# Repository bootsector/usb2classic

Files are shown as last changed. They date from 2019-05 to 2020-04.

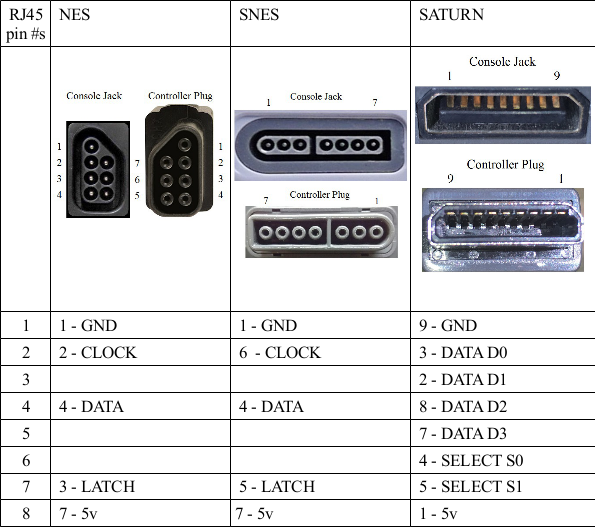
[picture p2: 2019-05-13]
doc/rj45_output_cables.png

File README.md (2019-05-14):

# USB2Classic - USB controllers adapter for retro consoles!
(c) Bruno Freitas - 04/2019 - http://www.brunofreitas.com/  

This project is Open Source (GPLv3) and Open Hardware (CC BY-SA 4.0)  

I've bought some super-cheap STM8S 8-bit microcontroller based boards and I 
was wondering what kind of cool project I could put them to use. I've mixed
it with an USB Host Mini 2.0 module a CPLD and some discrete components and
then the USB2Classic adapter was born!

This adapter allows you to use USB controllers with old consoles, such as:

* Sega Genesis / Mega Drive (can emulate either a 3 button or 6 button pad)
* Sega Master System, Atari 2600 and others
* Panasonic 3DO
* NES
* Super NES
* Sega Saturn
* Neo Geo
* TG16/PC-Engine (through adapter board connected to the Neo Geo output)

Currently compatible USB controllers are:

* Playstation 4 USB controller
* XBOX 360 USB controller (and compatible XInput devices)
* XBOX 360 USB Wireless Receiver
* 8BitDo Wireless USB Adapter (in XInput mode)
* Some PS3/PS4/XBOX360 USB arcade stick controllers

The CPLD originally used by this adapter is an EPM7064SLC44-10N which is 5V
based. Verilog sources are inside the multi-out directory along with Quartus II
project files.

The USB Host Mini board **MUST** be modified for 5V as shown in the
doc/usbhost_mini_5v_mod.png diagram.

Firmware was compiled using SDCC version 3.8.0

Thanks to Bruno Duarte Gouveia (brNX) for all the help with Verilog!

Enjoy!

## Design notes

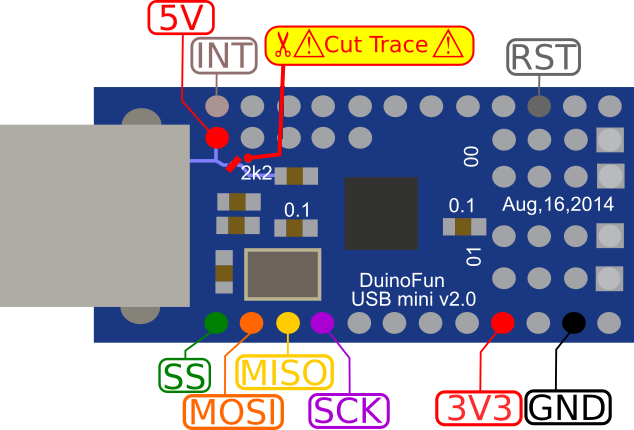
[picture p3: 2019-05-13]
doc/usbhost_mini_5v_mod.png

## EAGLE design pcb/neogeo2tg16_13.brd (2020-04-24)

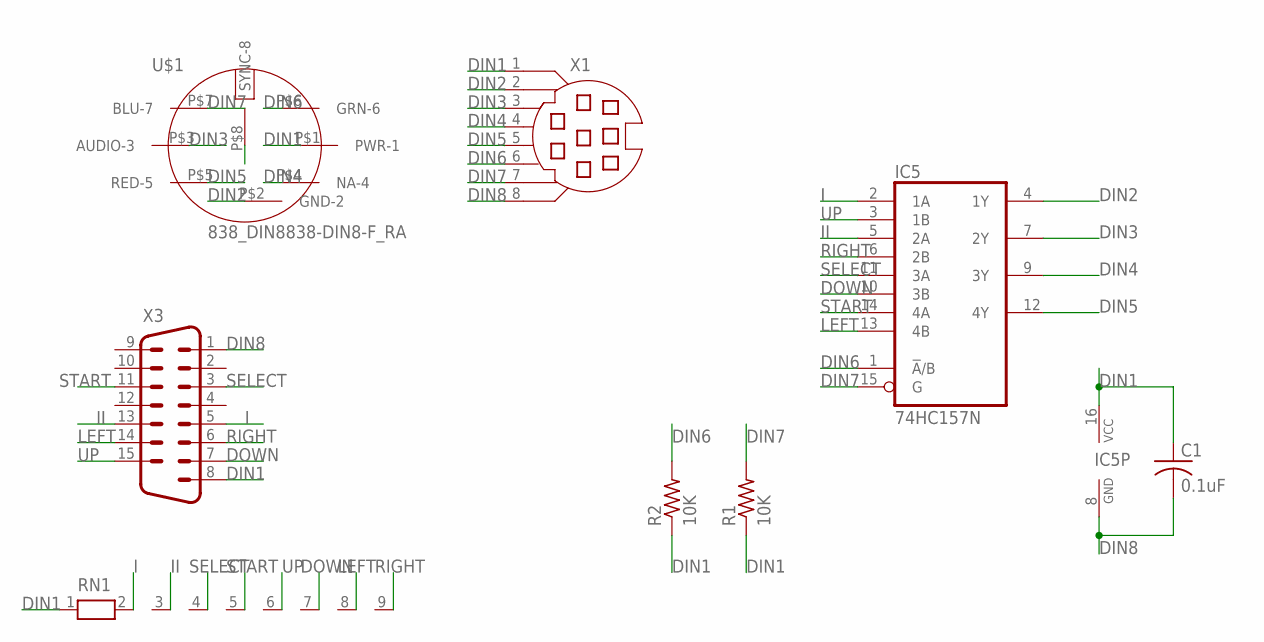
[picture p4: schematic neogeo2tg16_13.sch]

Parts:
C1: 0.1uF; C025-024X044
IC5: 74HC157N; DIL16
R1, R2: 10K; 0204/7
RN1: RN08; RN-9
U$1: 838_DIN8838-DIN8-F_RA; 838_DIN8
X1: MD08SS; MDIN08SS
X3: M15HP

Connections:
DIN1: C1.1, IC5.16 (VCC), R1.1, R2.1, RN1.1, U$1.P$1 (PWR-1), X1.1, X3.8
DIN2: IC5.4 (1Y), U$1.P$2 (GND-2), X1.2
DIN3: IC5.7 (2Y), U$1.P$3 (AUDIO-3), X1.3
DIN4: IC5.9 (3Y), U$1.P$4 (NA-4), X1.4
DIN5: IC5.12 (4Y), U$1.P$5 (RED-5), X1.5
DIN6: IC5.1 (!A!/B), R2.2, U$1.P$6 (GRN-6), X1.6
DIN7: IC5.15 (G), R1.2, U$1.P$7 (BLU-7), X1.7
DIN8: C1.2, IC5.8 (GND), U$1.P$8 (SYNC-8), X1.8, X3.1
DOWN: IC5.10 (3B), RN1.7, X3.7
I: IC5.2 (1A), RN1.2, X3.5
II: IC5.5 (2A), RN1.3, X3.13
LEFT: IC5.13 (4B), RN1.8, X3.14
RIGHT: IC5.6 (2B), RN1.9, X3.6
SELECT: IC5.11 (3A), RN1.4, X3.3
START: IC5.14 (4A), RN1.5, X3.11
UP: IC5.3 (1B), RN1.6, X3.15

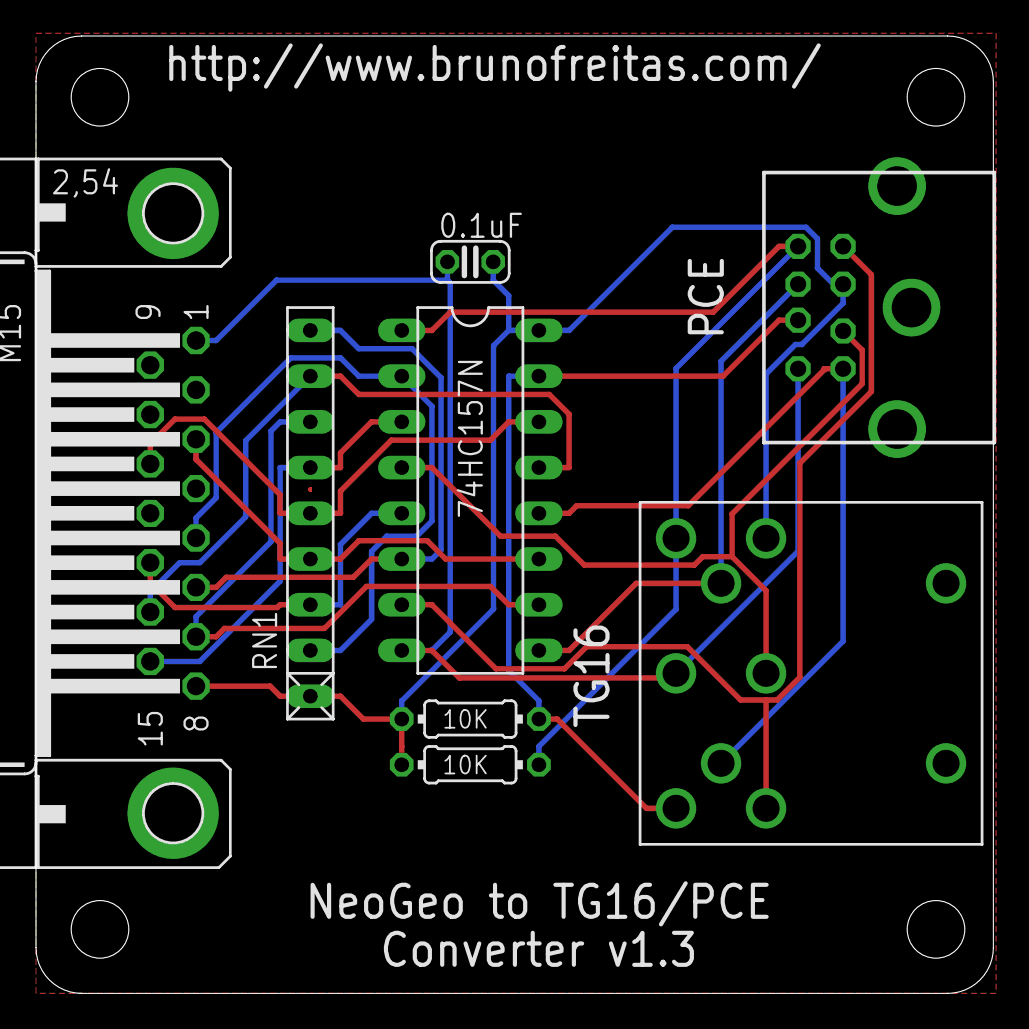
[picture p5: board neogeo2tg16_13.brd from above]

Board: 2 copper layers, 53.2 x 53.2 mm, 8 parts (0 on the bottom side), 16 nets.

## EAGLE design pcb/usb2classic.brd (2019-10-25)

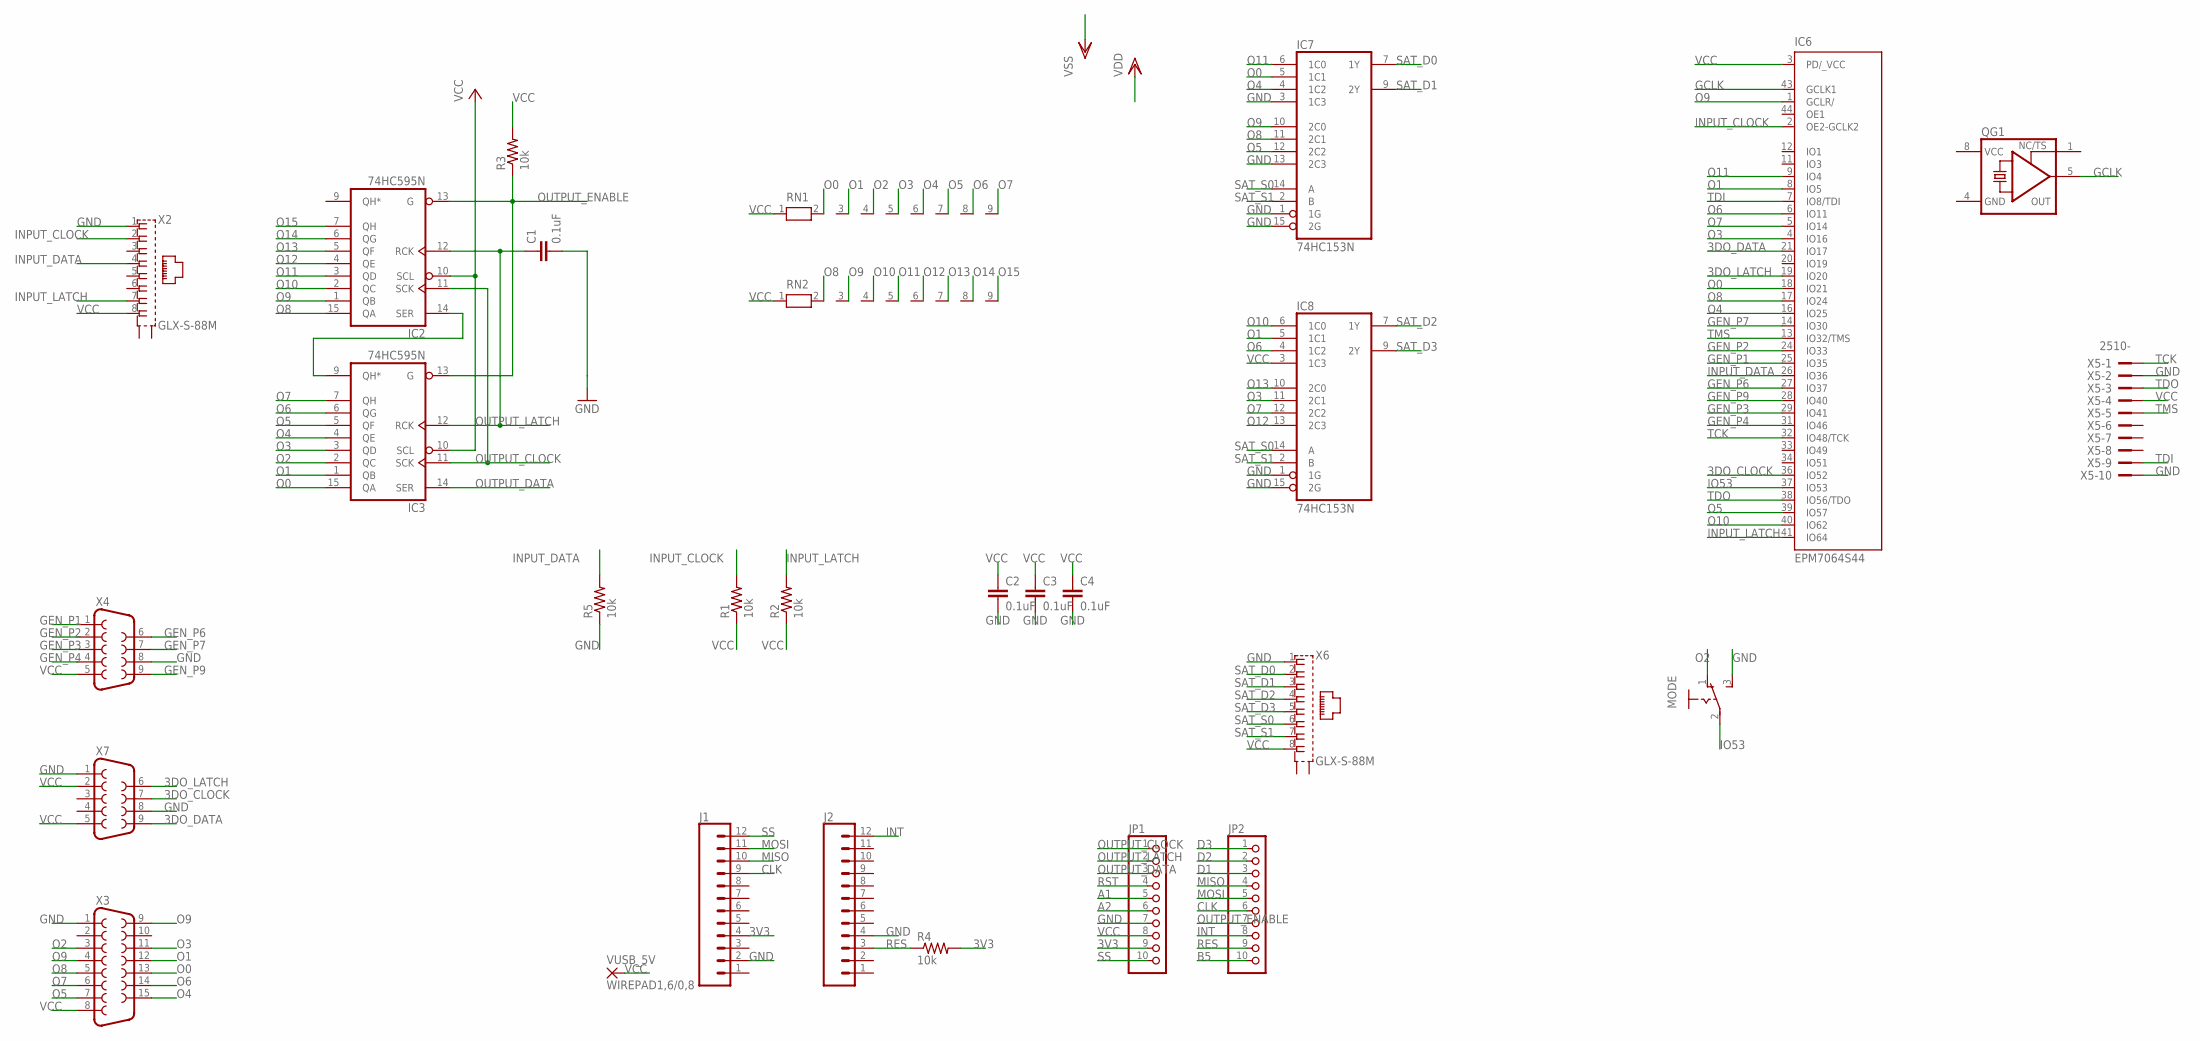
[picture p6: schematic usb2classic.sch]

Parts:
C1, C2, C3, C4: 0.1uF; C050-024X044
IC2, IC3: 74HC595N; DIL16
IC6: EPM7064S44; PLCC-S44
IC7, IC8: 74HC153N; DIL16
J1, J2: CONN_12; 1X12
JP1, JP2: PINHD-1X10; 1X10
MODE: CHAVE
QG1: XO-8; DIL08S
R1, R2, R3, R4, R5: 10k; 0207/10
RN1, RN2: RN08; RN-9
VUSB_5V: WIREPAD1,6/0,8; 1,6/0,8
X2, X6: GLX-S-88M
X3: F15HP
X4, X7: F09HP
X5: 2510-; PAK100/2500-10

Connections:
3DO_CLOCK: IC6.36 (IO52), X7.7
3DO_DATA: IC6.21 (IO17), X7.9
3DO_LATCH: IC6.19 (IO20), X7.6
3V3: J1.4, JP1.9, R4.2
A1: JP1.5
A2: JP1.6
B5: JP2.10
CLK: J1.9, JP2.6
D1: JP2.3
D2: JP2.2
D3: JP2.1
GCLK: IC6.43 (GCLK1), QG1.5 (OUT)
GEN_P1: IC6.25 (IO35), X4.1
GEN_P2: IC6.24 (IO33), X4.2
GEN_P3: IC6.29 (IO41), X4.3
GEN_P4: IC6.31 (IO46), X4.4
GEN_P6: IC6.27 (IO37), X4.6
GEN_P7: IC6.14 (IO30), X4.7
GEN_P9: IC6.28 (IO40), X4.9
GND: C1.2, C2.2, C3.2, C4.2, IC2.8 (GND), IC3.8 (GND), IC6.10 (GND), IC6.22 (GND), IC6.30 (GND), IC6.42 (GND), IC7.1 (1G), IC7.3 (1C3), IC7.8 (GND), IC7.13 (2C3), IC7.15 (2G), IC8.1 (1G), IC8.8 (GND), IC8.15 (2G), J1.2, J2.4, JP1.7, MODE.3 (S), QG1.4 (GND), R5.1, X2.1, X3.1, X4.8, X5.2, X5.10, X6.1, X7.1, X7.8
INPUT_CLOCK: IC6.2 (OE2-GCLK2), R1.2, X2.2
INPUT_DATA: IC6.26 (IO36), R5.2, X2.4
INPUT_LATCH: IC6.41 (IO64), R2.2, X2.7
INT: J2.12, JP2.8
IO53: IC6.37 (IO53), MODE.2
MISO: J1.10, JP2.4
MOSI: J1.11, JP2.5
unnamed: IC2.14 (SER), IC3.9 (QH*)
O0: IC3.15 (QA), IC6.18 (IO21), IC7.5 (1C1), RN1.2, X3.13
O1: IC3.1 (QB), IC6.8 (IO5), IC8.5 (1C1), RN1.3, X3.12
O2: IC3.2 (QC), MODE.1 (O), RN1.4, X3.3
O3: IC3.3 (QD), IC6.4 (IO16), IC8.11 (2C1), RN1.5, X3.11
O4: IC3.4 (QE), IC6.16 (IO25), IC7.4 (1C2), RN1.6, X3.15
O5: IC3.5 (QF), IC6.39 (IO57), IC7.12 (2C2), RN1.7, X3.7
O6: IC3.6 (QG), IC6.6 (IO11), IC8.4 (1C2), RN1.8, X3.14
O7: IC3.7 (QH), IC6.5 (IO14), IC8.12 (2C2), RN1.9, X3.6
O8: IC2.15 (QA), IC6.17 (IO24), IC7.11 (2C1), RN2.2, X3.5
O9: IC2.1 (QB), IC6.1 (GCLR/), IC7.10 (2C0), RN2.3, X3.4, X3.9
O10: IC2.2 (QC), IC6.40 (IO62), IC8.6 (1C0), RN2.4
O11: IC2.3 (QD), IC6.9 (IO4), IC7.6 (1C0), RN2.5
O12: IC2.4 (QE), IC8.13 (2C3), RN2.6
O13: IC2.5 (QF), IC8.10 (2C0), RN2.7
O14: IC2.6 (QG), RN2.8
O15: IC2.7 (QH), RN2.9
OUTPUT_CLOCK: IC2.11 (SCK), IC3.11 (SCK), JP1.1
OUTPUT_DATA: IC3.14 (SER), JP1.3
OUTPUT_ENABLE: IC2.13 (G), IC3.13 (G), JP2.7, R3.1
OUTPUT_LATCH: C1.1, IC2.12 (RCK), IC3.12 (RCK), JP1.2
RES: J2.3, JP2.9, R4.1
RST: JP1.4
SAT_D0: IC7.7 (1Y), X6.2
SAT_D1: IC7.9 (2Y), X6.3
SAT_D2: IC8.7 (1Y), X6.4
SAT_D3: IC8.9 (2Y), X6.5
SAT_S0: IC7.14 (A), IC8.14 (A), X6.6
SAT_S1: IC7.2 (B), IC8.2 (B), X6.7
SS: J1.12, JP1.10
TCK: IC6.32 (IO48/TCK), X5.1
TDI: IC6.7 (IO8/TDI), X5.9
TDO: IC6.38 (IO56/TDO), X5.3
TMS: IC6.13 (IO32/TMS), X5.5
VCC: C2.1, C3.1, C4.1, IC2.10 (SCL), IC2.16 (VCC), IC3.10 (SCL), IC3.16 (VCC), IC6.3 (PD/_VCC), IC6.15 (VCC), IC6.23 (VCC), IC6.35 (VCC), IC7.16 (VCC), IC8.3 (1C3), IC8.16 (VCC), JP1.8, QG1.8 (VCC), R1.1, R2.1, R3.2, RN1.1, RN2.1, VUSB_5V.1, X2.8, X3.8, X4.5, X5.4, X6.8, X7.2, X7.5

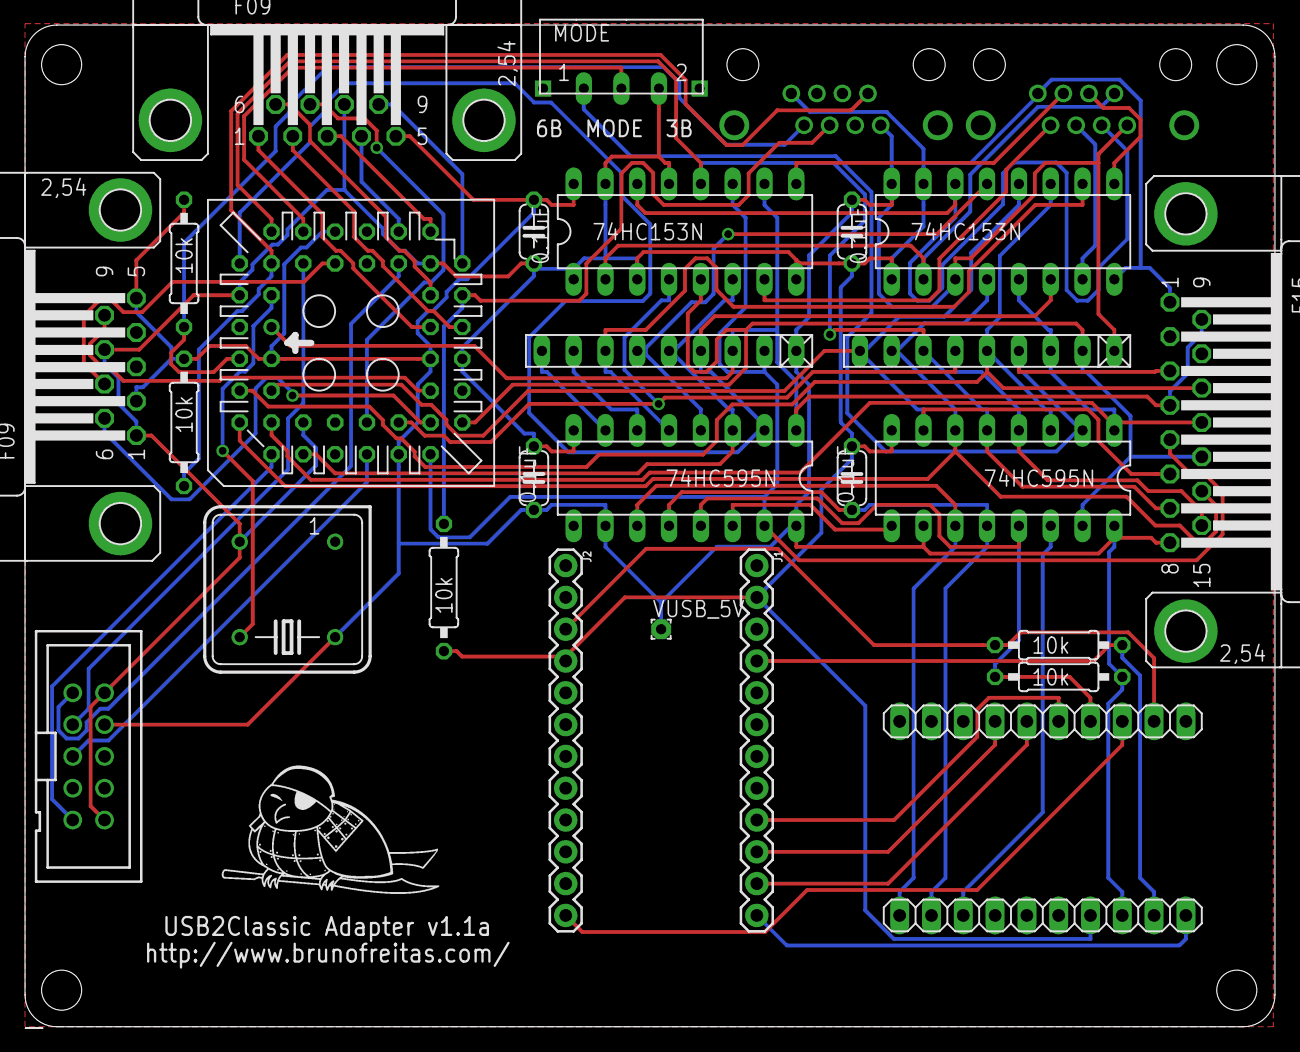
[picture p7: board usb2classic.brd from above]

Board: 2 copper layers, 99.8 x 80.0 mm, 29 parts (0 on the bottom side), 55 nets.

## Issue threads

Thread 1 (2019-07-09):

Some SNES consoles require a pull-down resistor in the DATA line

bootsector, 2019-07-09:
Although it's working fine on several NES consoles, in some SNES consoles it might be necessary a 10K pull-down resistor in the DATA line (INPUT_DATA/IO36).

Reason for this needs further investigation, but adding the 10K pull-down seems to fix the issue.

bootsector, 2019-09-11:
Pull down resistor seems to fix it.

requeijaum, 2019-09-19:
Remember to add a switch for that pull down resistor. Murphy's Law...

Closed 2019-09-11.

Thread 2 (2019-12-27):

How would a RJ45 to DB9 (Megadrive) cable be wired ?

eleriaqueen, 2019-12-27:
Hi, I ordered a usb2classic some time ago and with it a RJ45 -> Super Nintendo cable.
My brother got an Analogue Mega SG (Megadrive FPGA console) for christmas and I would like to use my usb2classic with it, so I'm considering making a cable myself.
Which leads me to the question : How would a RJ45 to DB9 cable be wired ?
Also it would be great if more RJ45 to Retro Consoles pinouts were included in the "Doc" folder. (I only see NES / SNES and Saturn)

Thanks in advance, and thanks for your hard work !

bootsector, 2020-01-11:
DB9 (Sega Genesis, etc...) and DB15 (NeoGeo and 3DO) cables are simple male-female extension cables. They don't use the RJ45 interface, as there are specific DB9 and DB15 connectors on-board for them.

This is the DB9 extension cable I recommend for connecting USB2Classic to the Mega Sg/Genesis:

https://www.ebay.com/itm/Original-1990-Heavy-Duty-High-Quality-6-Ft-Extension-Cables-Cable-Sega-Genesis/173203942822 (non-affiliated link)

Closed 2020-01-11.

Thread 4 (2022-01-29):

Will Dreamcast support be implemented?

badass-boss, 2022-01-29:
As the title says- will it be possible to use USB controllers and connect them to Dreamcast with this in the future or maybe even right now?? I'm talking about simple button controllers, support for VMUs isn't needed. Please reply, thanks in advance

bootsector, 2022-01-29:
There are no plans. You can achieve this with the RetroPad32 plus an USB Input Module and a DC output cable. However the RetroPad32 isn’t open source unfortunately.

Closed 2022-01-29.

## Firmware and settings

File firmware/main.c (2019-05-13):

/*
 * USB2Classic - USB controllers adapter for retro consoles!
 * Copyright (c) 2019 Bruno Freitas - bruno@brunofreitas.com
 *
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
 * You should have received a copy of the GNU General Public License
 * along with this program.  If not, see <http://www.gnu.org/licenses/>.
 */
#include "stm8s.h"
#include "delay.h"
#include "usb_in.h"
#include "multiout.h"

static AbstractPad_t pad_data;

static void Set16MhzInternalClock() {
	disableInterrupts();

	CLK_ICKR = 0;                   //  Reset the Internal Clock Register.
	CLK_ICKR = 1 << 0;              //  Enable the HSI.
	
	while (!(CLK_ICKR & (1 << 1))); //  Wait for HSIRDY.
	
	CLK_CKDIVR = 0;                 //  Ensure the clocks are running at full speed.
	CLK_SWR = 0xE1;                 //  Use HSI as the clock source.
	CLK_SWCR = 0;                   //  Reset the clock switch control register.
	CLK_SWCR = 1 << 1;              //  Enable switching.
	
	while (CLK_SWCR & (1 << 0));    //  Pause while the clock switch is busy.

	enableInterrupts();
}

void main() {
	/* Set internal clock to 16Mhz */
	Set16MhzInternalClock();

	/* Reset pad data buffer */
	ResetBuffer(&pad_data);

	/* Initialize USB input and serial output drivers */
	usb_in_init();
	multiout_init();

	/* Main polling loop */
	for(;;) {
		usb_in_get_pad_state(&pad_data);
		multiout_update(&pad_data);
	}
}

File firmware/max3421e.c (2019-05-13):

/*
 * USB2Classic - USB controllers adapter for retro consoles!
 * Copyright (c) 2019 Bruno Freitas - bruno@brunofreitas.com
 *
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
 * You should have received a copy of the GNU General Public License
 * along with this program.  If not, see <http://www.gnu.org/licenses/>.
 */
#include "stm8s.h"

#include "max3421e.h"

#include "delay.h"

static volatile uint8_t spi_transceive_status;

static void max3421e_spi_transceive_begin() {
	bit_clear(PC_ODR, 1 << 5); // CLK LOW
	bit_clear(PA_ODR, 1 << 3); // SS LOW

	__asm__("nop\nnop\n");
}

static void max3421e_spi_transceive_end() {
	__asm__("nop\nnop\n");

	bit_clear(PC_ODR, 1 << 5); // CLK LOW
	bit_set(PA_ODR, 1 << 3); // SS HIGH
}

static uint8_t max3421e_spi_transceive_byte(uint8_t data) {
	uint8_t readval = 0;

	__asm__("nop\nnop\n");

	// The MAX3421E changes its output data (MISO) on the falling edge of SCLK
	// and samples input data (MOSI) on the rising edge of SCLK.
	for(int8_t bit = 7; bit >= 0; bit--) {

		// MOSI
		if(data & (1 << bit)) {
			bit_set(PC_ODR, 1 << 6);
		} else {
			bit_clear(PC_ODR, 1 << 6);
		}

		bit_set(PC_ODR, 1 << 5); // CLK HIGH

		// MISO
		if(bit_check(PC_IDR, 7)) {
			readval |= (1 << bit);
		}

		bit_clear(PC_ODR, 1 << 5); // CLK LOW
	}

	__asm__("nop\nnop\n");

	return readval;
}

uint8_t max3421e_spi_last_transceive_status() {
	return spi_transceive_status;
}

void max3421e_write_byte(uint8_t reg, uint8_t value) {
	reg = (reg << 3) | 2;

	max3421e_spi_transceive_begin();

	spi_transceive_status = max3421e_spi_transceive_byte(reg);

	max3421e_spi_transceive_byte(value);

	max3421e_spi_transceive_end();
}

void max3421e_write_buffer(uint8_t reg, uint8_t *data, int len) {
	reg = (reg << 3) | 2;

	max3421e_spi_transceive_begin();

	spi_transceive_status = max3421e_spi_transceive_byte(reg);

	for(int i = 0; i < len; i++) {
		max3421e_spi_transceive_byte(data[i]);
	}

	max3421e_spi_transceive_end();
}

uint8_t max3421e_read_byte(uint8_t reg) {
	uint8_t readval;

	reg = (reg << 3);

	max3421e_spi_transceive_begin();

	spi_transceive_status = max3421e_spi_transceive_byte(reg);

	readval = max3421e_spi_transceive_byte(0x00);

	max3421e_spi_transceive_end();

	return readval;
}

void max3421e_read_buffer(uint8_t reg, uint8_t *data, int len) {
	reg = (reg << 3);

	max3421e_spi_transceive_begin();

	spi_transceive_status = max3421e_spi_transceive_byte(reg);

	for(int i = 0; i < len; i++) {
		data[i] = max3421e_spi_transceive_byte(0x00);
	}

	max3421e_spi_transceive_end();
}

void max3421e_reset() {
	bit_clear(PB_ODR, 1 << 4); // RES LOW
	
	delay_us(1);

	bit_set(PB_ODR, 1 << 4);; // RES HIGH
}

uint8_t max3421e_int_state() {
	return bit_check(PC_IDR, 3);
}

void max3421e_init() {
	/* Init SPI pins */

	// PC5 - CLK
	// PC6 - MOSI
	// PC7 - MISO
	// PA3 - SS
	// PC3 - INT
	// PB4 - RES

	// MISO (Input Pull Up)
	bit_clear(PC_DDR, 1 << 7);
	bit_set(PC_CR1, 1 << 7);

	// MOSI (push pull output, fast mode)
	bit_set(PC_DDR, 1 << 6);
	bit_set(PC_CR1, 1 << 6);
	bit_set(PC_CR2, 1 << 6);

	// SS (push pull output, fast mode)
	bit_set(PA_DDR, 1 << 3);
	bit_set(PA_CR1, 1 << 3);
	bit_set(PA_CR2, 1 << 3);

	// CLK (push pull output, fast mode)
	bit_set(PC_DDR, 1 << 5);
	bit_set(PC_CR1, 1 << 5);
	bit_set(PC_CR2, 1 << 5);

	bit_clear(PC_ODR, 1 << 5); // CLK
	bit_clear(PC_ODR, 1 << 6); // MOSI
	bit_set(PA_ODR, 1 << 3);   // SS

	/* Init INT pin */

	// INT (Input Floating)
	bit_clear(PC_DDR, 1 << 3);
	bit_clear(PC_CR1, 1 << 3);

	/* Init RES pin */

	// RES - output open drain
	bit_set(PB_DDR, 1 << 4);
	bit_clear(PB_CR1, 1 << 4);
	bit_clear(PB_CR2, 1 << 4);

	bit_set(PB_ODR, 1 << 4);   // RES is HIGH (open drain)

	spi_transceive_status = 0;
}

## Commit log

2019-05-13 Initial release
    [neogeo2tg16_12.brd, neogeo2tg16_12.sch, usb2classic.brd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]
2019-05-16 Adding SVG and PDF for acrylic case
2019-05-16 Add support to Toodles MC Cthulhu USB board
2019-05-25 Decreasing brightness of Dualshock 4 as it was drawing too much current
2019-05-25 Added support to Brook Universal Board (Forced PS4 Mode)
2019-06-22 Added button mapping reference
    [button_map.xlsx]
2019-08-07 Added pull-down resistor to NES/SNES data line. This is an attempt to fix issue #1
    [usb2classic.brd, usb2classic.sch]
2019-10-03 Adding support for extra button mappings
2019-10-03 Added one more button map config
2019-10-03 Updated button mapping document
    [button_map.ods, button_map.xlsx]
2019-10-04 Added one more config map
    [button_map.ods]
2019-10-04 Mappings optimizations
    [button_map.ods]
2019-10-04 Mapping corrections
    [button_map.ods]
2019-10-19 Removed combos for home button. Map switching is now done with Up + Home. Updated map 4. Updated mapping doc
    [button_map.ods]
2019-10-25 Removed not used signal traces from the CPLD
    [usb2classic.brd, usb2classic.sch]
2019-10-29 Support right analog stick as alternative to buttons for Xeno Crisis on Sega Genesis
2020-04-24 Fixed start button not working in the NeoGeo to TG16 adapter
    [neogeo2tg16_13.brd, neogeo2tg16_13.sch]
2020-08-09 Getting rid of async external signals for NES/SNES and 3DO encoders.

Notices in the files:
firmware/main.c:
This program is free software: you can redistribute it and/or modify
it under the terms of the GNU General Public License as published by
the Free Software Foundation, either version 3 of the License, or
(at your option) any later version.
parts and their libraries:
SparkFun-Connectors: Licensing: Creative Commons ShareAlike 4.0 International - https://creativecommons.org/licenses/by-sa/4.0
